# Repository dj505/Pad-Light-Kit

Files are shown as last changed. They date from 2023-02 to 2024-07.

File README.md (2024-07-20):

# Overkill PIU Pad Lighting Kit
An upgrade kit, if you consider a 5x5 RGB LED grid in the center of each panel to be an upgrade.  

Demo

# What is this?
I wanted to make a drop-in kit that replaced the original LEDs in Pump it Up dance pads with fancy StepManiaX-like RGB lighting. **This is only partially that.** Due to a variety of factors, it's not quite as drop-in as I'd hoped, but installation is still rather straightforward!

There are 2 PCB designs being worked on for this project:
* The main "Panel" PCB
    * Contains all the LEDs, with individual microcontrollers per PCB, ensuring they can all work individually.
    * Fully tested, with updated design/gerber files that hardware issues I initially ran into while prototyping.
* The power distrubution PCB
    * Takes a barrel jack and/or bare wires via screw terminals.
    * 5V input only! Make sure your power supply can pump out enough amps to power all the LEDs.
    * 5 outputs, one per arrow on one pad. In the case of DDR/ITG pads, one may be left unused.
    * Also includes footprints for filtering capacitors, which I haven't found to be necessary. Populate with 10uF 0805 capacitors if needed.

Unlike the PicoFX and my other previous hardware projects, this kit is not meant to be hand-soldered, although hand-solder friendly footprints were used where possible. As this likely will not be sold as a pre-made kit any time soon, be aware that it is not a beginner project. PCB manufacturing and assembly costs are rather affordable, but costs from part sourcing and shipping could add up.

# Compatibility & Overview

### This project is designed to be as easy as possible to install, but does require you to do some amount of manual part sourcing. Please pay close attention to power consumption and make sure you source parts that can support the kit.

This project is made for somewhat modern Pump it Up dance pads (FX through LX), but is plug-and-play compatible with:
* All Pump it Up dance pads **after** SD (SD pads used incandescent bulbs and will require some modification for use with this kit)
* In the Groove pads
* Older Dance Dance Revolution pads that use the same 2.54mm pitch connector (double check first!)
Please **pay close attention to the polarity** of the 12V connector printed on the PCB's silkscreen.  
The **yellow wire should go to 12V.** This may involve plugging the cable in upside down. That's okay. Just keep in mind the pins may need to be bent upwards slightly to accept the connector.

Without some modification to the pads and/or this kit, this project is untested or **NOT** plug-and-play compatible with:
* Pump it Up JUMP pads (unfortunate, I know)
* Modern Dance Dance Revolution pads
* Namco "Crapocab" DDR pads
* StepManiaX pads (for several reasons)
* Dance Master Super Station/3DDX
* EZ2Dancer
If the pads you want to use this project with have a **12V DC** wire that powers the original lights, whether it goes to existing LEDs or to an inverter, **this kit will function, but may require you to cut the wires and/or splice in a new connector.** It likely will also not fit the original mounting holes, in which case you'll need to tape it down or something.

Aside from the individual components required for each PCB, you will need:
* As many "Panel" PCBs as your upgrade requires
    * PIU pads require 5 per full pad, 10 in total for a complete setup
    * ITG/DDR pads require 4 per full pad, 8 in total for a complete setup
* A way to supply 5V with up to ~10A maximum current draw (50W or so)
    * This can be either one 5A power supply **per pad**, or one single super beefy power supply for **both pads simultaneously.**
    * If I did my math right, these metrics are based on the peak power comsumption when every single LED is lit up white at full brightness. **Only run your LEDs on full-brightness white for extended periods of time at your own risk; the kit was not developed with this use in mind.** (It would be bright as heck, though)
* Extra wiring to supply power to the new PCBs
    * I recommend 20AWG, anything thinner is not rated for the possible peak power consumption of one panel
* 2 pin male JST connectors (along with metal connector to be crimped to the wires)
    * These are listed here separately from the female connectors in the bill of materials, as you'll need quite a few.
    * 2 connectors are required per panel. One to connect to the lighting PCB, one to connect to the power distribution board.
* A crimping tool compatible with JST XH connectors (optional, but recommended)

# Main panel PCB
A full BOM can be generated using KiCad's schematic editor. Unlike my previous projects, such as the PicoFX or PicoIO, there are a *lot* of components that you will likely need to source yourself. Many of these have LCSC part numbers attached as an example, but are not guaranteed to be available through JLCPCB's assembly service.  
The following components (some of which are not required) are listed per **single** PCB:

### Bill of materials
| Component | Reference | Footprint |Quantity|
|---|---|---|---|
|100nF Capacitor |C1, C2, C4, C5, C7-C9, C12, C14, C15 |SMD 0402 |10 |
|1uF Capacitor |C3, C6 |SMD 0402 |2 |
|27pF Capacitor |C10, C11 |SMD 0402 |2 |
|10uF Capacitor |C13, C16 |SMD 0402 |2 |
|WS2812B-V5 LED (!) |D1-10, D12-26 |PLCC4 5x5mm |25 |
|SS34 Diode |D27 |DO-214AC |1 |
|Green LED |D28 |SMD 0805 |1 |
|nSMD025 Fuse |F1 |SMD 1206 |1 |
|3 Pin Header \* |J1 |2.54mm Pitch |1 |
|USB Type C Port |J2 |G-Switch GT-USB 7010ASV |1 |
|2 Pin JST XH |J3 |2.50mm Pitch |1 |
|2x6 Pin Header \* |J4 |2.54mm Pitch |1 |
|Molex 35312-0760 \~\~ |J5 |N/A |1 |
|Molex Mini-Fit Jr \~\~ |J6-J9 |N/A |4 |
|2 Pin Header \~ |J10 |2.54mm Pitch, **Horizontal**|1 |
|3 Pin Header \*\* |J11, J12 |1.27mm Pitch, Not Required  |2 |
|1k Ohm Reistor |R1, R8, R10 |SMD 0402 |3 |
|10k Ohm Resistor |R2 |SMD 0402 |1 |
|10K Ohm Resistor \*\* |R3 |SMD 0402 (for SPI flash) |1 |
|27 Ohm Resistor |R4, R5 |SMD 0402 |2 |
|5.1k Ohm Resistor |R6, R7 |SMD 0402 |2 |
|3k Ohm Resistor |R9 |SMD 0402 |1 |
|Tactile Button Switch |SW1, SW2 |6mm x 6mm |2 |
|W25Q32JVSS (or equivalent) |U1 |SOIC-8 |1 |
|Raspberry Pi RP2040 |U2 |QFN-56 |1 |
|NCP1117 3.3V Output Regulator|U3 |SOT-223-3 |1 |
|12.000MHz Crystal Oscillator |Y1 |HC49 |1 |

(!) WS2812B-V5 LEDs don't require external capacitors, so there are no footprints for them on this board. Earlier revisions may not work properly without these capacitors.
\* Optional  
\*\* Do Not Fit (only required if a part malfunctions without it)  
\~ Required for old-style pads (FX and earlier)  
\~\~ Required for new-style pads (CX/TX and newer)  

All **SMD 0402** parts use hand-solder footprints in just in case, however if you do not own a reflow oven or hot air soldering station, please consider using an assembly service available through companies like PCBWay or JLCPCB for a better and more realiable end result. It does cost extra, but will be far less time consuming and far more reliable than soldering hundreds of components by hand.

# Power PCB
This part is extremely basic and just supplies power to the panels. Each PCB should be capable of supplying up to 8A, enough to power all 5 panels. Just make sure to hook it up to a power supply capable of delivering the necessary wattage.

### Bill of materials
| Component | Reference | Footprint |Quantity|
|---|---|---|---|
|10uF Capacitor \* |C1-C5 |SMD 0805 |5 |
|2 Pin Screw Terminal \*\* |J1 |5mm Plugin Terminal |1 |
|DC Barrel Jack \*\* |J2 |2.5mm inner, 6.4mm Outer |1 |
|2 Pin JST XH |J3-J7 |2.50mm Pitch |5 |

\* Option/not strictly necessary. Serves a purpose, but shouldn't affect functionality if missing.  
\*\* Denotes parts that are interchangeable depending on how you want to power the board

This board lacks mounting holes and is intended to just be attached somewhere near the foot PCB or power supply with double sided tape. Placement is up to you. Footprints for a screw terminal and a DC jack are provided, depending on which is more suited to your use case. You could even solder the power wires straight to the PCB if you really want to.  

JST XH connectors with 20AWG wire will need to be routed from the power distrubution PCB to every individual panel PCB. This shouldn't be all that difficult, just a little extra time consuming. Having a crimping tool would make this far easier.

# Very Important Notes
**(Seriously, you're going to want to double check these!)**

### This kit will require dedicated external power, and there's no safe way around that!
This kit bumps the LED count up to 125 per pad. Stock pads have around 40 or fewer depending on pad model. Please don't try to power this off the cab's original 12V line! The original 22AWG wire is rated for roughly 0.92A. This kit can potentially draw up to 1A per panel, or 5A total per pad. Plus, the 12V line is used for signalling purposes with this kit, and it won't function correctly without it. **I've measured a draw of 0.874A for a single panel lit up white at full brightness, however this may not be consistent from build to build.** While 10A total is a worst-case scenario, be sure to stick to the following guidelines:  
* Make sure you use a power supply that's capable of supplying the necessary amount of power required by this kit, and pick a wire gauge capable of carrying the amount of power needed for each panel. I would recommend 20AWG.  
* You'll need a way to run power into the pads. If I can come up with a more elegant solution I'll be sure to post it in detail, but the holes present in the bottom corners of each arrow are safe bets as entry points for your wires.
* Even if you don't plan on running these at high enough power to draw 5A per pad (or the maximum you have measured on your own), don't skimp out on a power supply. Overdrawing the power supply will cause it to get uncomfortably warm (or worse), and will eventually destroy it. Spend the extra few bucks for safety!

### Make sure you use a bright solder mask!
White is recommended, green and others may also work, but black solder mask isn't known to be very reflective. It won't make a very big difference, but it will definitely look better and brighter.

### If you own a multimeter, check the voltage of the 12V line!
These boards get their "turn on and start animating" signal from the original 12V wiring that's meant to power the stock LEDs/inverters/what have you. To make this safe for the 3.3V RP2040 chip, a voltage divider is used. Until this design is eventually replaced with an optoisolator or other component, **you should do the following:**  
1. Unplug the stock LED
2. Hook up a voltmeter or a multimeter in DC mode to the connector
3. Ensure the connector supples **no less than 10V** and **no more than 13.2V** when supplying power  
If your measurement falls outside of this range and the power supply in your cab isn't adjustable, you may need to use different reistors for the voltage divider circuit.

If the connector is not supplying enough power, the microcontroller won't read it as a "high" signal to start animating the lights. If it's *too* high, you risk damaging the microcontroller. I've haven't seen any machines deviate from this general range before, so chances are you're fine, but make sure to double check. If your machine has a variable voltage power supply **and you know what you're doing**, you can adjust it slightly to fit within the safe range.

# Firmware Setup
This project runs on [CircuitPython for the Raspberry Pi Pico.](https://circuitpython.org/board/raspberry_pi_pico/). I'm not quite clever enough to create a special CircuitPython build specifically for this project yet, maybe one day!

1. Download the .uf2 file for CircuitPython. This project was developed using 7.3.3, but in between writing the firmware and actually receiving all the parts for a kit, 8.0.0 was released as a stable version, so the following instructions have been updated.
2. Plug the board into your PC. The BOOTSEL button shouldn't need to be held as the board should not yet be programmed. If for some reason it already is, use the BOOTSEL button.
3. The board should pop up as a USB mass storage device. Drag and drop the .uf2 file onto it. After a moment, it should disconnect, and you should see a "CIRCUITPY" drive appear in its place.
4. Open the "CIRCUITPY" drive, and copy the contents of this repository's "Firmware" directory onto it, overwriting code.py.
5. Download the [CircuitPython library bundle](https://circuitpython.org/libraries) that matches the version of CircuitPython you installed.
    * Look inside the "lib" directory for an "asyncio" folder. Copy this to the CIRCUITPY drive's "lib" folder.
    * Do the same for "adafruit_pixelbuf.mpy", "adafruit_ticks.mpy", and "neopixel.mpy".
6. Create your animations. See the instructions in /Firmware/README.md or use the included example animations.
    * Your animation should be a bitmap file titled "image.bmp" and located in the "bitmap" directory.
    * By default, there won't be a "bitmap" directory. You'll need to create this by hand or copy over the example one.
7. You're done! If everything is assembled and set up properly, your animations should now work, and the panel is ready to be installed.

# Installation
After assembling and setting up the firmware for each of the panels, actually installing them is the easy part. I'll update this section with photos when I have some.

1. Unplug and remove the original LEDs, and replace them with the new boards.
    * If the mounting holes *do* line up, use the original screws to secure the new boards in place.
    * If the mounting holes *don't* line up, double sided tape will do the trick!
    * You may have to remove some original parts to make room, depending on the pad. This mostly applies to much older pads that have fluorescent lights hooked up to inverters. Carefully remove these (they may be fragile!) and set them aside.
2. Find a power supply, and plan out where the wires are going to go.
    * I find the easiest way to do this is to hide the power supply underneath the dance pad and run the cable coming from the low voltage side in through the one of the 4 holes in the bottom of one of the arrow panels.
    * I would not recommend routing any AC wiring or power supply units inside of the dance pads for safety reasons. It's much safer to run the low voltage DC side in alone.
3. Mount the power distribution PCB.
    * Make sure it's within easy reach of the cable you'll be using to power it.
    * The placement here is entirely up to your discretion, just put it somewhere that allows you to easily run all the necessary wires. I mounted mine under the center panel.
    * This PCB has no mounting holes, since you'll be using double sided tape or other similar adhesive to mount it. Make sure any exposed contacts on the bottom are trimmed down and/or covered and so they do not make contact with the pad frame.
4. Run wires from the distribution board's outputs to each of your panels.
    * If you know what you're doing, and you thoroughly test the power consumption of your components, be sure to use a wire rated for the power draw. Otherwise, I recommend 20AWG wire. I personally measured a 0.874A peak power draw, but your build may differ.
    * You can either try to source wires with JST XH connectors on either end, or you can crimp these yourself.
    * If you crimp these yourself, buy a crimping tool! They don't cost a lot and they make things way way less of a pain. (They're still kind of a pain, though.)
    * Double check that the positive/negative connections line up on both sides of your wires.
5. Fire it up and give it a test!
    * If something doesn't work, move onto the troubleshooting section.

# Jumper Options
These jumpers are currently unused. Please feel free to reach out and suggest features!

# Bypassing the Voltage Divider
There's a small set of jumper pads underneath and to the right of the connector for the 12V light header header that is meant to bypass the voltage divider. This is meant to allow the panel to be easily used in home pads or DIY pads using an Arduino-like main board. **Do not bridge this jumper if using anything higher than a 3.3V to control the lights.**

To use this feature, you must:
* Make sure you remove resistors R9 and R10 underneath the header if they are currently installed. Otherwise, exclude these components during the initial asssembly.
* Make sure the GPIO you're going to connect this to operates at a **3.3 volt logic level!** The RP2040 is **not 5V tolerant** and applying 5V to the GPIO can cause irreversible damage.

If you plan to use a 5V microcontroller, you must **not** bridge the jumper, and should instead adjust the values of the resistors in the voltage divider accordingly.

# Troubleshooting
This list will be expanded as potential issues crop up.
* **No lights or pattern on the LED grid**
    1. Make sure the bitmap is in the "bitmap" directory, and is named "bitmap.bmp".
    2. Check that external power is connected. A USB connection will not power the LEDs.
    3. Re-export your bitmap through GIMP with the correct settings:
        * 24-bit colour depth
        * Run-length encoding **disabled**
        * Saving colour space information doesn't seem to make a difference, but if in doubt, disable it
* **Pattern displays, but doesn't look right**
    1. Make sure your spritesheet is made up of exactly 5x5 pixel sprites, all of which should be stacked vertically. More than one column will not work.
    2. Re-export your bitmap through GIMP with the correct settings. See step 3 under "No lights or pattern on the LED grid."
* **All the LEDs past a certain point fail to light up**
    1. Check the solder points on and around the LED where the chain is broken.
        * The strip goes from left to right on the first row, then right to left on the second row, zigzagging back and forth.
        * If any single LED is not properly connected, it can either light up but not send a signal to the next one, or fail to light up itself.
        * Carefully re-solder any bad connections and test again.
    2. Ensure the LEDs are oriented correctly.
        * With the USB port on the top left corner, the notch on every LED should be on the bottom right side.
        * Any LEDs that aren't oriented properly will need to be desoldered and rotated.
* **One single LED doesn't light up, but the rest work**
    1. Add some flux to each leg of the LED and reflow the solder.
        * Screwing the PCB down into the pad may slightly bend it, causing a poor connection on one or more LEDs.
        * Reflowing the solder usually fixes this fault. Current revisions of the PCB with slightly larger mounting holes should be less susceptible to it.

# Credits
Thanks to:
- [sugoku](https://github.com/sugoku) for the Molex 35312 series footprints

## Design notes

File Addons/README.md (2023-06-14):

# Addons
Various addons for the Overkill Pad Lighting Kit

## What do these do?
* Comms **(Rev. 2 and earlier panel PCBs)**
  * Adds RS485 communication to each board to sync lighting data.
* Comms Controller **(Rev. 2 and earlier panel PCBs)**
  * Will act as a central unit for uploading new lighting patterns, ideally using a Raspberry Pi Pico W hosting a web interface.

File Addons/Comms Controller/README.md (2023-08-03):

# Comms Controller
This addon is meant for **all current revisions** of the Pad Light Kit main board. As of writing, the current revision is **Rev. 3.**

This addon allows patterns to be uploaded to the main board(s) over RS485. Don't mix up the RS485 and power connectors!

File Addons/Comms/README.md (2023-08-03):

# Comms
This addon is made for **panel PCB rev. 2 and earlier**. Revision 3 has this functionality built-in and it is no longer necessary.

The "Comms" addon is meant to allow each panel to communicate robustly using RS485 through SP3485 chips to synchronize lighting patterns and other settings.

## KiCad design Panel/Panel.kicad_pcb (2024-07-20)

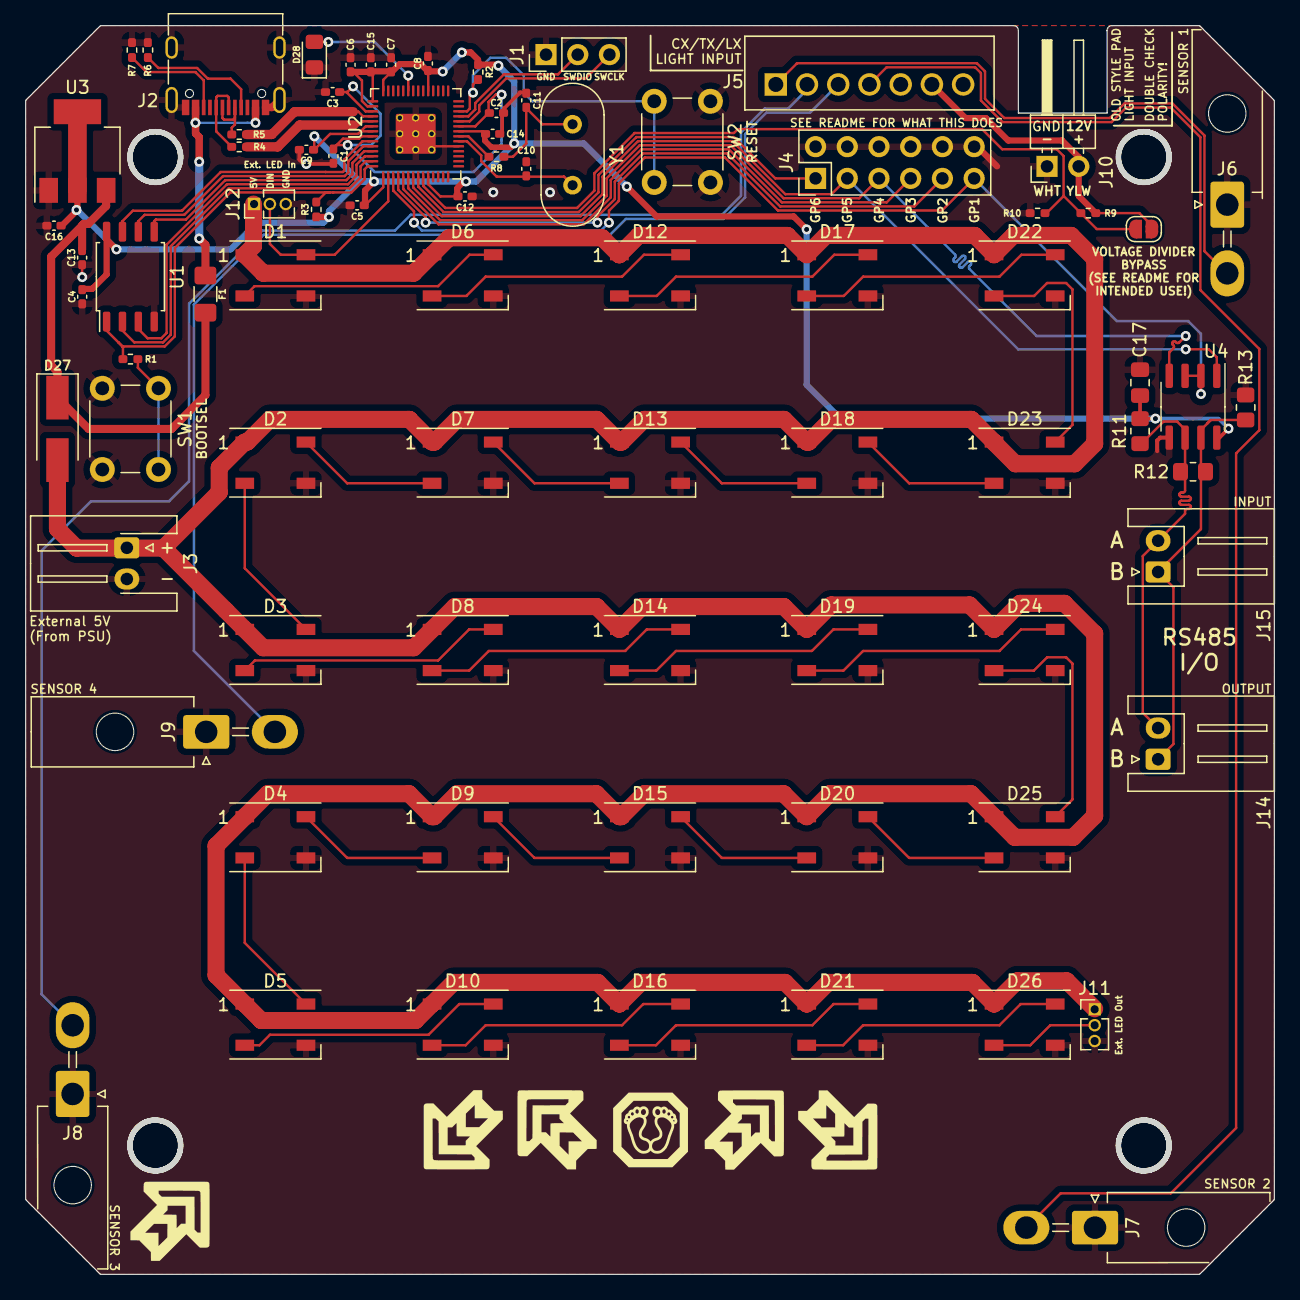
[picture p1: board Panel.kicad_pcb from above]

Board: 2 copper layers, 100.0 x 100.0 mm, 80 parts (0 on the bottom side), 66 nets.

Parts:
C1, C2, C4, C5, C7, C8, C9, C12, C14, C15: 100nF; C_0402_1005Metric_Pad0.74x0.62mm_HandSolder
C3, C6: 1uF; C_0402_1005Metric_Pad0.74x0.62mm_HandSolder
C10, C11: 27pF; C_0402_1005Metric_Pad0.74x0.62mm_HandSolder
C13, C16: 10uF; C_0402_1005Metric_Pad0.74x0.62mm_HandSolder
C17: 100nF; C_0805_2012Metric_Pad1.18x1.45mm_HandSolder
D1, D2, D3, D4, D5, D6, D7, D8, D9, D10, D12, D13, D14, D15, D16, D17, D18, D19, D20, D21, D22, D23, D24, D25, D26: WS2812B; LED_WS2812B_PLCC4_5.0x5.0mm_P3.2mm
D27: SS34; D_SMA_Handsoldering
D28: LED_Small; LED_0805_2012Metric_Pad1.15x1.40mm_HandSolder
F1: 500mA; Fuse_1206_3216Metric_Pad1.42x1.75mm_HandSolder
J1: Conn_01x03; PinHeader_1x03_P2.54mm_Vertical
J2: USB_C_Receptacle_USB2.0; USB_C_Receptacle_G-Switch_GT-USB-7010ASV
J3: Conn_01x02; JST_XH_S2B-XH-A-1_1x02_P2.50mm_Horizontal
J4: Conn_02x06_Odd_Even; PinHeader_2x06_P2.54mm_Vertical
J5: Conn_01x07; 35312-0760
J6, J7, J8, J9: Conn_01x02; Molex_Mini-Fit_Jr_5569-02A2_2x01_P4.20mm_Horizontal
J10: Conn_01x02; PinHeader_1x02_P2.54mm_Horizontal
J11, J12: Conn_01x03; PinHeader_1x03_P1.27mm_Vertical
J14, J15: Conn_01x02; JST_XH_S2B-XH-A_1x02_P2.50mm_Horizontal
JP1: Jumper_2_Open; SolderJumper-2_P1.3mm_Open_RoundedPad1.0x1.5mm
R1, R8, R10: 1k; R_0402_1005Metric_Pad0.72x0.64mm_HandSolder
R2: 10k; R_0402_1005Metric_Pad0.72x0.64mm_HandSolder
R3: DNF; R_0402_1005Metric_Pad0.72x0.64mm_HandSolder
R4, R5: 27 Ohm; R_0402_1005Metric_Pad0.72x0.64mm_HandSolder
R6, R7: 5.1k; R_0402_1005Metric_Pad0.72x0.64mm_HandSolder
R9: 3k; R_0402_1005Metric_Pad0.72x0.64mm_HandSolder
R11, R13: 4.7k; R_0805_2012Metric_Pad1.20x1.40mm_HandSolder
R12: 120; R_0805_2012Metric_Pad1.20x1.40mm_HandSolder
SW1, SW2: SW_Push; SW_PUSH_6mm
U1: W25Q32JVSS; SOIC-8_5.23x5.23mm_P1.27mm
U2: RP2040; RP2040-QFN-56
U3: NCP1117-3.3_SOT223; SOT-223-3_TabPin2
U4: SP3485EN; SOIC-8_3.9x4.9mm_P1.27mm
Y1: 12.000MHz; Crystal_HC49-4H_Vertical

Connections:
+1V1: C1.1, C2.1, C3.1, U2.23 (DVDD), U2.45 (VREG_VOUT), U2.50 (DVDD)
+3V3: C4.1, C5.1, C6.1, C7.1, C8.1, C9.1, C12.1, C14.1, C15.1, C16.1, C17.1, R2.1, R3.1, R11.1, U1.8 (VCC), U2.1 (IOVDD), U2.10 (IOVDD), U2.22 (IOVDD), U2.33 (IOVDD), U2.42 (IOVDD), U2.43 (ADC_AVDD), U2.44 (VREG_IN), U2.48 (USB_VDD), U2.49 (IOVDD), U3.2 (VO), U4.8 (VCC)
+5V: C13.1, D27.1 (K), F1.2, U3.3 (VI)
/RS485_A: J14.2, J15.2, R11.2, R12.1, U4.6 (A)
/RS485_B: J14.1, J15.1, R12.2, R13.1, U4.7 (B)
Ext 5V: D1.1 (VDD), D2.1 (VDD), D3.1 (VDD), D4.1 (VDD), D5.1 (VDD), D6.1 (VDD), D7.1 (VDD), D8.1 (VDD), D9.1 (VDD), D10.1 (VDD), D12.1 (VDD), D13.1 (VDD), D14.1 (VDD), D15.1 (VDD), D16.1 (VDD), D17.1 (VDD), D18.1 (VDD), D19.1 (VDD), D20.1 (VDD), D21.1 (VDD), D22.1 (VDD), D23.1 (VDD), D24.1 (VDD), D25.1 (VDD), D26.1 (VDD), D27.2 (A), J3.1, J11.1, J12.1
GND: C1.2, C2.2, C3.2, C4.2, C5.2, C6.2, C7.2, C8.2, C9.2, C10.1, C11.1, C12.2, C13.2, C14.2, C15.2, C16.2, C17.2, D1.3 (VSS), D2.3 (VSS), D3.3 (VSS), D4.3 (VSS), D5.3 (VSS), D6.3 (VSS), D7.3 (VSS), D8.3 (VSS), D9.3 (VSS), D10.3 (VSS), D12.3 (VSS), D13.3 (VSS), D14.3 (VSS), D15.3 (VSS), D16.3 (VSS), D17.3 (VSS), D18.3 (VSS), D19.3 (VSS), D20.3 (VSS), D21.3 (VSS), D22.3 (VSS), D23.3 (VSS), D24.3 (VSS), D25.3 (VSS), D26.3 (VSS), D28.1 (K), J1.1, J2.A1 (GND), J2.A12 (GND), J2.B1 (GND), J2.B12 (GND), J2.S1 (SHIELD), J3.2, J4.2, J4.4, J4.6, J4.8, J4.10, J4.12, J5.7, J6.1, J7.1, J8.1, J9.1, J10.1, J11.3, J12.3, R6.2, R7.1, R10.2, R13.2, SW1.1, SW2.2, U1.4 (GND), U2.19 (TESTEN), U2.57 (GND), U3.1 (GND), U4.5 (GND)
GPIO0: D1.4 (DIN), J12.2, U2.2 (GPIO0)
GPIO1: J4.11, U2.3 (GPIO1), U4.2 (~RE), U4.3 (DE)
GPIO2: J4.9, U2.4 (GPIO2)
GPIO3: J4.7, U2.5 (GPIO3)
GPIO4: J4.5, U2.6 (GPIO4), U4.4 (DI)
GPIO5: J4.3, U2.7 (GPIO5), U4.1 (RO)
GPIO6: J4.1, U2.8 (GPIO6)
GPIO7: JP1.1 (A), R9.2, R10.1, U2.9 (GPIO7)
LIGHT EN: J5.6, J10.2, JP1.2 (B), R9.1
unnamed: C11.2, R8.1, Y1.1
unnamed: D1.2 (DOUT), D6.4 (DIN)
unnamed: D2.4 (DIN), D7.2 (DOUT)
unnamed: D2.2 (DOUT), D3.4 (DIN)
unnamed: D3.2 (DOUT), D8.4 (DIN)
unnamed: D4.4 (DIN), D9.2 (DOUT)
unnamed: D4.2 (DOUT), D5.4 (DIN)
unnamed: D5.2 (DOUT), D10.4 (DIN)
unnamed: D10.2 (DOUT), D16.4 (DIN)
unnamed: D6.2 (DOUT), D12.4 (DIN)
unnamed: D12.2 (DOUT), D17.4 (DIN)
unnamed: D13.4 (DIN), D18.2 (DOUT)
unnamed: D7.4 (DIN), D13.2 (DOUT)
unnamed: D8.2 (DOUT), D14.4 (DIN)
unnamed: D14.2 (DOUT), D19.4 (DIN)
unnamed: D15.4 (DIN), D20.2 (DOUT)
unnamed: D9.4 (DIN), D15.2 (DOUT)
unnamed: D16.2 (DOUT), D21.4 (DIN)
unnamed: D17.2 (DOUT), D22.4 (DIN)
unnamed: D18.4 (DIN), D23.2 (DOUT)
unnamed: D19.2 (DOUT), D24.4 (DIN)
unnamed: D20.4 (DIN), D25.2 (DOUT)
unnamed: D21.2 (DOUT), D26.4 (DIN)
unnamed: D22.2 (DOUT), D23.4 (DIN)
unnamed: D24.2 (DOUT), D25.4 (DIN)
unnamed: D26.2 (DOUT), J11.2
unnamed: D28.2 (A), U2.37 (GPIO25)
unnamed: F1.1, J2.A4 (VBUS), J2.A9 (VBUS), J2.B4 (VBUS), J2.B9 (VBUS)
unnamed: J2.A5 (CC1), R6.1
unnamed: J2.B5 (CC2), R7.2
unnamed: R1.1, SW1.2
unnamed: R5.1, U2.46 (USB_DM)
unnamed: R4.1, U2.47 (USB_DP)
QSPI_SCLK: U1.6 (CLK), U2.52 (QSPI_SCLK)
QSPI_SD0: U1.5 (DI(IO0)), U2.53 (QSPI_SD0)
QSPI_SD1: U1.2 (DO(IO1)), U2.55 (QSPI_SD1)
QSPI_SD2: U1.3 (IO2), U2.54 (QSPI_SD2)
QSPI_SD3: U1.7 (IO3), U2.51 (QSPI_SD3)
QSPI_SS: R1.2, R3.2, U1.1 (~CS), U2.56 (QSPI_SS)
RUN: R2.2, SW2.1, U2.26 (RUN)
SENSOR 1: J5.1, J6.2
SENSOR 2: J5.4, J7.2
SENSOR 3: J5.2, J8.2
SENSOR 4: J5.3, J9.2
SWCLK: J1.3, U2.24 (SWCLK)
SWDIO: J1.2, U2.25 (SWD)
USB D+: J2.A6 (D+), J2.B6 (D+), R4.2
USB D-: J2.A7 (D-), J2.B7 (D-), R5.2
XIN: C10.2, U2.20 (XIN), Y1.2
XOUT: R8.2, U2.21 (XOUT)

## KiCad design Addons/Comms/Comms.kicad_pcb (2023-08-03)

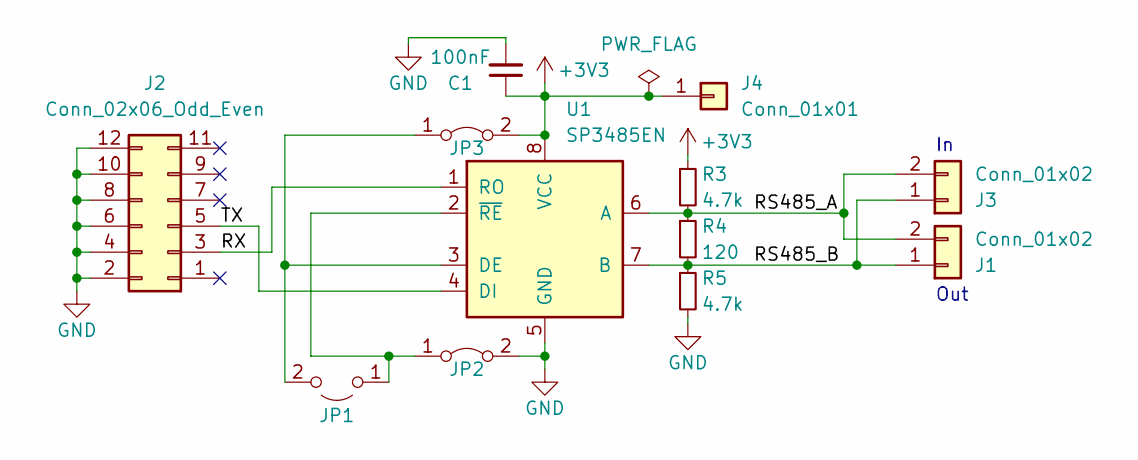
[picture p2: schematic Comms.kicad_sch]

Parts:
C1: 100nF; C_0805_2012Metric_Pad1.18x1.45mm_HandSolder; LCSC C49678
J1, J3: Conn_01x02; JST_XH_S2B-XH-A_1x02_P2.50mm_Horizontal
J2: Conn_02x06_Odd_Even; PinHeader_2x06_P2.54mm_Vertical
J4: Conn_01x01; PinHeader_1x01_P2.54mm_Vertical
JP1: Jumper_2_Open; SolderJumper-2_P1.3mm_Open_RoundedPad1.0x1.5mm
JP2, JP3: Jumper_2_Bridged; SolderJumper-2_P1.3mm_Bridged_RoundedPad1.0x1.5mm
R3, R5: 4.7k; R_0805_2012Metric_Pad1.20x1.40mm_HandSolder; LCSC C17673
R4: 120; R_0805_2012Metric_Pad1.20x1.40mm_HandSolder; LCSC C17437
U1: SP3485EN; SOIC-8_3.9x4.9mm_P1.27mm; LCSC C8963

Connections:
+3V3: C1.1, J4.1, JP3.2 (B), R3.1, U1.8 (VCC)
/RS485_A: J1.2, J3.2, R3.2, R4.1, U1.6 (A)
/RS485_B: J1.1, J3.1, R4.2, R5.1, U1.7 (B)
/RX: J2.3, U1.1 (RO)
/TX: J2.5, U1.4 (DI)
GND: C1.2, J2.2, J2.4, J2.6, J2.8, J2.10, J2.12, JP2.2 (B), R5.2, U1.5 (GND)
unnamed: JP1.1 (A), JP2.1 (A), U1.2 (~RE)
unnamed: JP1.2 (B), JP3.1 (A), U1.3 (DE)

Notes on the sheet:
Out

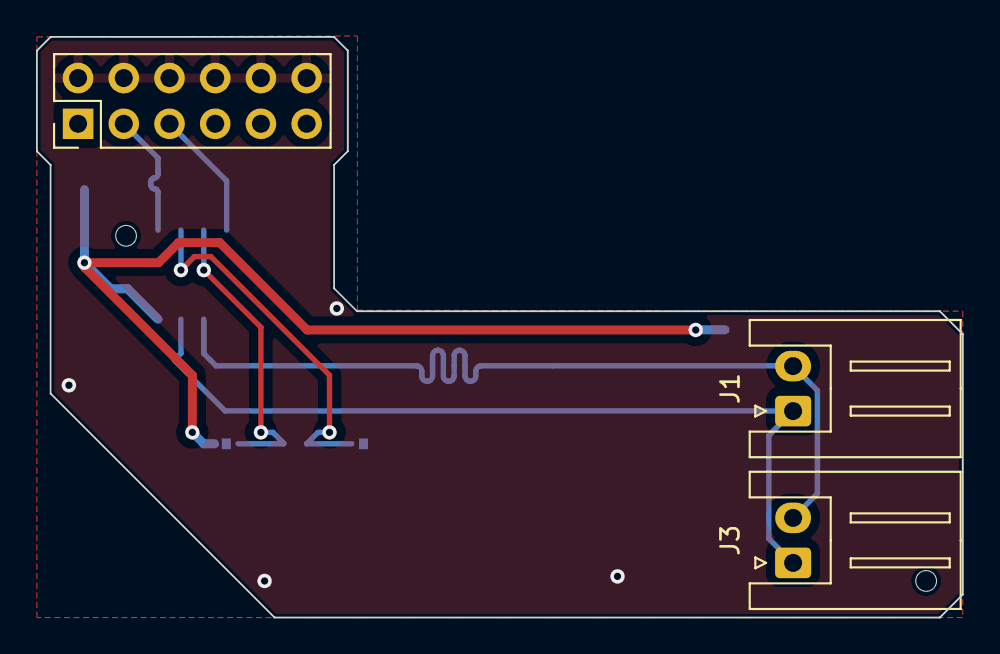
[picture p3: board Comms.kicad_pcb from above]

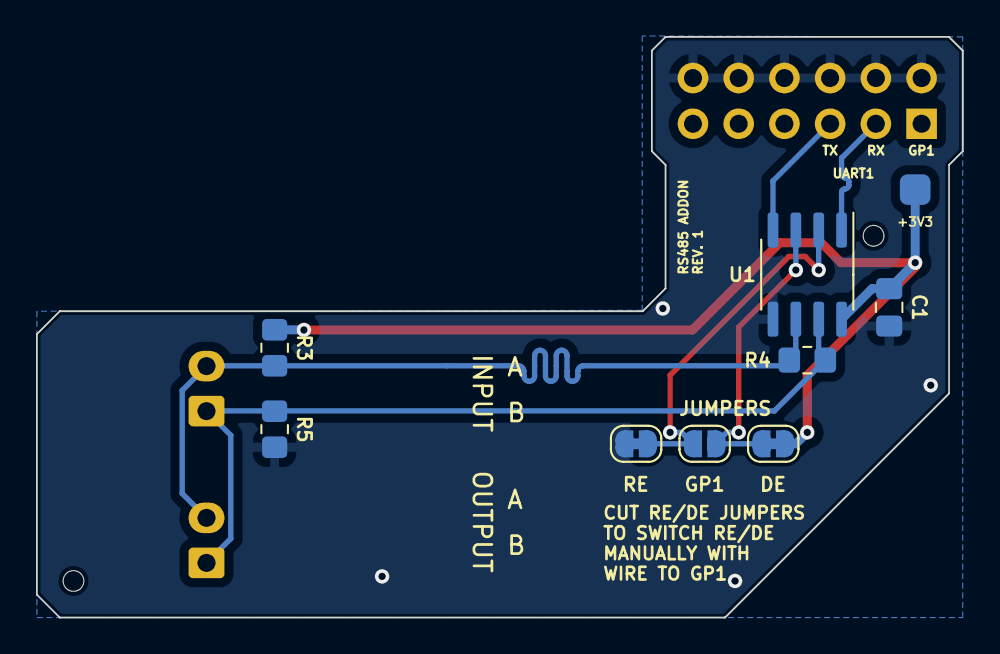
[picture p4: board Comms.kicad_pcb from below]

Board: 2 copper layers, 51.4 x 32.3 mm, 12 parts (9 on the bottom side), 8 nets.

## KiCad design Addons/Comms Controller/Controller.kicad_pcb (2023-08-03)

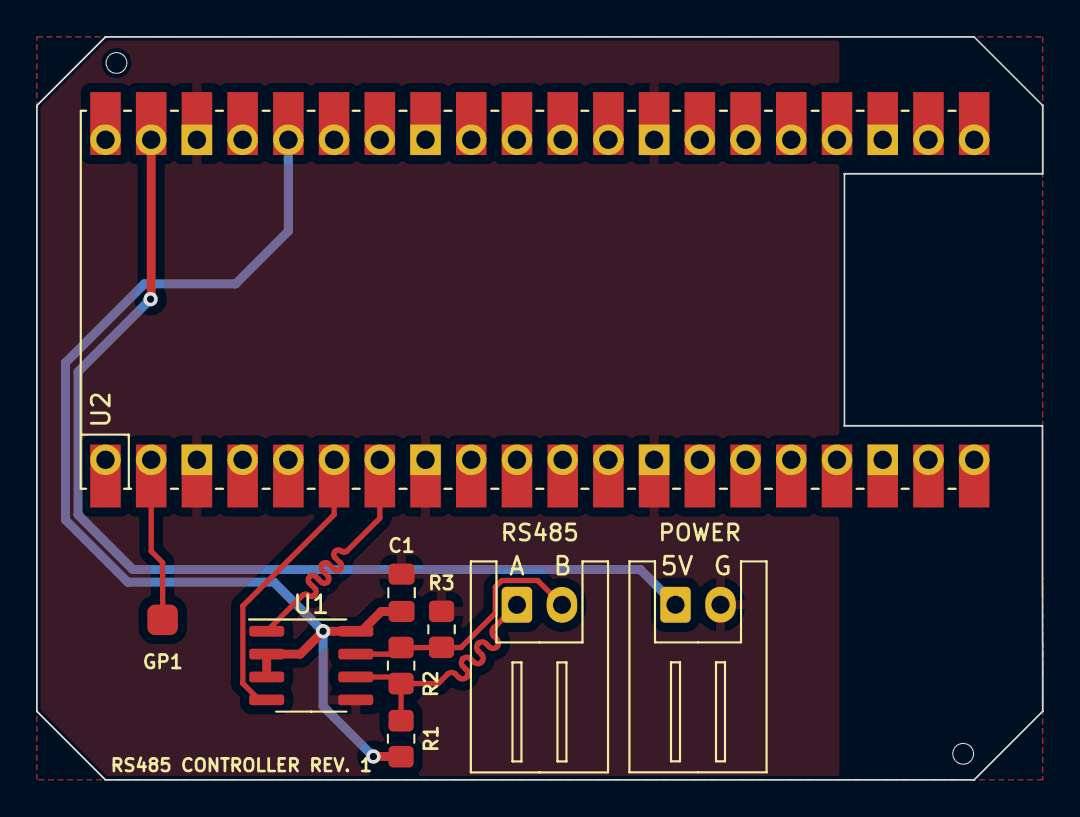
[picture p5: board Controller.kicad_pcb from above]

Board: 2 copper layers, 55.9 x 41.3 mm, 9 parts (0 on the bottom side), 8 nets.

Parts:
C1: 100nF; C_0805_2012Metric_Pad1.18x1.45mm_HandSolder
J1: GP1 Bodge; PinSocket_1x01_P2.54mm_Vertical
J2, J3: Conn_01x02; JST_XH_S2B-XH-A_1x02_P2.50mm_Horizontal
R1, R3: 4.7k; R_0805_2012Metric_Pad1.20x1.40mm_HandSolder
R2: 120; R_0805_2012Metric_Pad1.20x1.40mm_HandSolder
U1: SP3485EN; SOIC-8_3.9x4.9mm_P1.27mm
U2: Pico; RPi_Pico_SMD_TH

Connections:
+3V3: C1.1, R1.1, U1.2 (~RE), U1.3 (DE), U1.8 (VCC), U2.36 (3V3)
+5V: J3.1, U2.39 (VSYS)
/RS485_A: J2.1, R1.2, R2.1, U1.6 (A)
/RS485_B: J2.2, R2.2, R3.1, U1.7 (B)
GND: C1.2, J3.2, R3.2, U1.5 (GND), U2.3 (GND), U2.8 (GND), U2.13 (GND), U2.18 (GND), U2.23 (GND), U2.28 (GND), U2.38 (GND)
unnamed: J1.1, U2.2 (GPIO1)
RX: U1.1 (RO), U2.7 (GPIO5)
TX: U1.4 (DI), U2.6 (GPIO4)

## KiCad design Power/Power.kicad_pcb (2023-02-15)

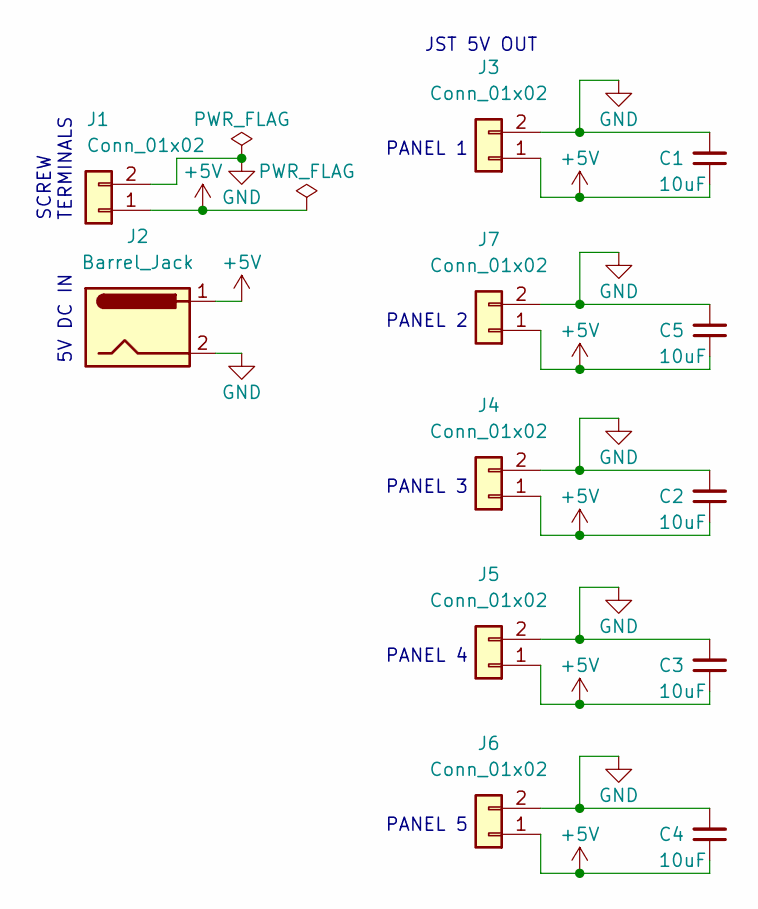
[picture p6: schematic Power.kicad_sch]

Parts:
C1, C2, C3, C4, C5: 10uF; C_0805_2012Metric_Pad1.18x1.45mm_HandSolder
J1: Conn_01x02; TerminalBlock_bornier-2_P5.08mm
J2: Barrel_Jack; BarrelJack_CUI_PJ-063AH_Horizontal
J3, J4, J5, J6, J7: Conn_01x02; JST_XH_B2B-XH-A_1x02_P2.50mm_Vertical

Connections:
+5V: C1.1, C2.1, C3.1, C4.1, C5.1, J1.1, J2.1, J3.1, J4.1, J5.1, J6.1, J7.1
GND: C1.2, C2.2, C3.2, C4.2, C5.2, J1.2, J2.2, J2.MP, J3.2, J4.2, J5.2, J6.2, J7.2

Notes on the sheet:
PANEL 4
JST 5V OUT
SCREW TERMINALS
PANEL 2
PANEL 1
5V DC IN
PANEL 3
PANEL 5

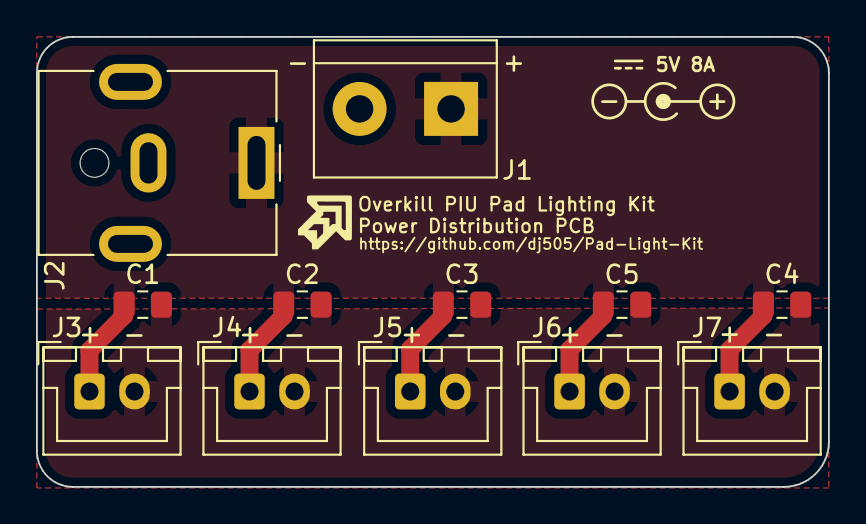
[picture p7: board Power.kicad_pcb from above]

Board: 2 copper layers, 44.0 x 25.0 mm, 12 parts (0 on the bottom side), 2 nets.

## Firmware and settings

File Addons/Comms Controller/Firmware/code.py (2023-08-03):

import board
import busio
import digitalio
import time
import ipaddress
import wifi
from adafruit_httpserver import Server, Request, Response, POST
import socketpool
import re
import json
import binascii

uart = busio.UART(board.GP4, board.GP5, baudrate=9600)

# Wifi stuff
ssid = "dkpepper"
pswd = "7808607880"
ip = "10.0.0.234"

ipv4 =  ipaddress.IPv4Address(ip)
netmask =  ipaddress.IPv4Address("255.255.255.0")
gateway =  ipaddress.IPv4Address("10.0.0.1")
wifi.radio.set_ipv4_address(ipv4=ipv4,netmask=netmask,gateway=gateway)
#  connect to your SSID
wifi.radio.connect(ssid, pswd)

print("Connected to WiFi")
pool = socketpool.SocketPool(wifi.radio)
server = Server(pool, "/static", debug=True)

def webpage():
    html = f"""
    <!DOCTYPE html>
        <html>
            <head>
                <meta http-equiv="Content-type" content="text/html;charset=utf-8">
                <meta name="viewport" content="width=device-width, initial-scale=1">
                <script>
                  document.addEventListener("DOMContentLoaded", function() {{
                    var DL = document.getElementById('DL');
                    var UL = document.getElementById('UL');
                    var CN = document.getElementById('CN');
                    var UR = document.getElementById('UR');
                    var DR = document.getElementById('DR');

                    function handleFileUpload(event) {{
                      event.preventDefault();
                      const file = event.target.files[0];
                      const boardID = event.currentTarget.ID
                      const reader = new FileReader();

                      reader.onload = function() {{
                        const base64Image = reader.result.split(',')[1];
                        console.log(base64Image);
                        sendImageToServer(base64Image, boardID);
                      }};
                      reader.readAsDataURL(file);
                    }};

                    function sendImageToServer(base64Image, ID) {{
                      const data = {{
                        image: base64Image,
                        boardID: ID
                      }};

                      const jsonData = JSON.stringify(data);

                      console.log(jsonData);

                      // Send the POST request
                      fetch('http://{ip}', {{
                        method: 'POST',
                        mode: 'cors',
                        headers: {{
                          'Content-Type': 'application/json'
                        }},
                        body: jsonData
                      }})
                      .then(response => response.json())
                      .then(result => {{
                        // Handle the response from the server
                        console.log('Server response:', result);
                      }})
                      .catch(error => {{
                        // Handle any errors
                        console.error('Error:', error);
                      }});
                    }};

                    DL.addEventListener('change', handleFileUpload);
                    DL.ID = "DL"
                    UL.addEventListener('change', handleFileUpload);
                    UL.ID = "UL"
                    CN.addEventListener('change', handleFileUpload);
                    CN.ID = "CN"
                    UR.addEventListener('change', handleFileUpload);
                    UR.ID = "UR"
                    DR.addEventListener('change', handleFileUpload);
                    DR.ID = "DR"
                  }});
                </script>
            </head>
            <body>
                <title>Pad Light Kit Thing :)</title>
                <h1>Overkill Pad Light Kit File Upload</h1>
                <form id="uploadForm">
                    <label for="DL">DownLeft Pattern</label><br>
                    <input type="file" id="DL"><br><br>
                    <label for="UL">UpLeft Pattern</label><br>
                    <input type="file" id="UL"><br><br>
                    <label for="CN">Center Pattern</label><br>
                    <input type="file" id="CN"><br><br>
                    <label for="UR">UpRight Pattern</label><br>
                    <input type="file" id="UR"><br><br>
                    <label for="DR">DownRight Pattern</label><br>
                    <input type="file" id="DR"><br><br>
                    <button>Upload</button>
                </form>
                <p id="opTag"></p>
            </body>
        </html>
    """
    return html

def decode_image(data):
    image = binascii.a2b_base64(data)
    return image

def uart_write(boardid, imagedata):
    n = 32
    strbytes = bytearray(f"<{boardid},{imagedata}>")
    bytechunks = [strbytes[i:i + n] for i in range(0, len(strbytes), n)]
    print(bytechunks)
    print(f"Writing UART Data")
    for chunk in bytechunks:
        print(chunk)
        uart.write(chunk)
        time.sleep(0.2)
    return True

@server.route("/")
def base(request: Request):
    return Response(request, f"{webpage()}", content_type='text/html')

@server.route("/", POST)
def buttonpress(request: Request):
    #  get the raw text
    request_content = request.json()
    print(request_content)
    image = decode_image(request_content["image"])
    boardid = request_content["boardID"]
    print("Starting UART write...")
    if uart_write(boardid, image):
        print("Finished UART write")

    return Response(request, f"{webpage()}", content_type='text/html')

print("starting server...")
# startup the server
try:
    server.start(str(wifi.radio.ipv4_address))
    print("Listening on http://%s:80" % wifi.radio.ipv4_address)
#  if the server fails to begin, restart the pico w
except OSError:
    time.sleep(5)
    print("restarting...")
    microcontroller.reset()

ping_address = ipaddress.ip_address("8.8.4.4")
clock = time.monotonic()
while True:
    try:
        if (clock + 30) < time.monotonic():
            if wifi.radio.ping(ping_address) is None:
                # print("Disconnected!")
                continue
            else:
                # print("Still connected")
                continue

            clock = time.monotonic()
        server.poll()
    except Exception as e:
        print(e)
        continue

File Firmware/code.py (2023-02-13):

import asyncio
import board
import digitalio
import neopixel
import struct

matrix = neopixel.NeoPixel(board.GP0, 25, brightness=1, auto_write=False)

sensor = digitalio.DigitalInOut(board.GP7)
sensor.direction = digitalio.Direction.INPUT
sensor.pull = digitalio.Pull.DOWN

frame_delay = 0.05 # Time between frames. Adjust to change playback speed
idle_brightness = 0.125
anim_brightness = 1

# Bitmap reading (with padding)
with open("bitmap/image.bmp", "rb") as f:
    # Read the file header
    f.seek(10)
    offset = struct.unpack("<i", f.read(4))[0]

    # Read the image header
    f.seek(18)
    width, height = struct.unpack("<ii", f.read(8))

    # Create a 2D array to store the pixel data
    pixels = [[(0, 0, 0) for _ in range(width)] for _ in range(height)]

    # Go to the pixel data
    f.seek(offset)

    # Read the pixel data
    for row in range(height - 1, -1, -1):
        for col in range(width):
            blue = ord(f.read(1))
            green = ord(f.read(1))
            red = ord(f.read(1))
            pixels[row][col] = (red, green, blue)

        # Calculate the number of padding bytes
        padding = (4 - (width * 3) % 4) % 4
        # Read the padding bytes and discard them
        f.read(padding)

pixels = sum(pixels, []) # Hacky magic to flatten the 2D list into a 1D list, because it doesn't need to be 2D.
                         # Will fix this later. Unless you're reading this, in which case it's a permanent feature now
frames = []
for i in range(0, len(pixels), 25):
    pixels[i + 5:i + 10] = pixels[i + 5:i + 10][::-1]   # The LED matrix is wired in alternating rows.
    pixels[i + 15:i + 20] = pixels[i + 15:i + 20][::-1] # As such, every 2nd "row" of each frame needs
    frames.append(pixels[i:i + 25])                     # to be mirrored.

ctrl = asyncio.Event() # Event to communicate whether the lights should be on or off to every async process
ctrl.clear() # Clear the event, so it's set as "False"
animation_task = None # Define the animation task as a global varbiale for ease of use. Don't cancel me for this, async is hard :(

async def animate(): # Self explanatory. Loops while animating
    matrix.brightness = anim_brightness
    while True:
        i = 0
        for frame in frames: # Loop through every frame, each made up of a 25 element long list holding the colour values for each pixel
            for dot in frame: # Loop through the colour values
                matrix[i] = dot # Assign the colour value to every LED in the matrix (actually just a strip of 25 LEDs chopped up, so we can treat it as one strip)
                i = 0 if (i+1) > 24 else i+1 # Necessary to prevent an index error
            matrix.show()
            await asyncio.sleep(frame_delay) # Async sleep, to make sure other code has time to run, as well as to keep the animation constrained to a certain speed
        await asyncio.sleep(0)

async def idle(): # Displays a single still frame, specifically the first frame in the animation, while panel isn't being held.
    i = 0
    for dot in frames[0]: # Only needs one loop because only the first frame is being accessed
        matrix[i] = dot   # Otherwise works identically to the animate() routine
        i = 0 if (i+1) > 24 else i+1 # Same deal as before
    matrix.brightness = idle_brightness
    matrix.show()

async def ctrl_detect():  # Constantly reads the state of the sensor pin to check if the panel should be animating.
    global animation_task # The signal is active high, so the 12V line that normally powers the panel's original LEDs
    while True:           # is going through a voltage divider to bring it down to a 3V "high" signal.
        if sensor.value:
            ctrl.set() # Set the "ctrl" event to "True" to tell the other subroutines that the animation should be playing
        else:
            ctrl.clear() # Clear the "ctrl" event to tell the other subroutines that the animation should stop, and the idle task should start
            if animation_task is not None: # Immediately stop the animation task if it's still playing.
                animation_task.cancel()    # Otherwise, the animation task and the idle task with clash,
                animation_task = None      # resulting in an unpleasant blinking effect.
                idle_task = asyncio.create_task(idle()) # Create and run the idle task.
                await idle_task
        await asyncio.sleep(0) # Allow other tasks time to execute

async def main(): # Main loop. Should be pretty self explanatory. Probably lots of redundant code here - might refactor later
    global animation_task
    idle_task = asyncio.create_task(idle())
    ctrl_task = asyncio.create_task(ctrl_detect())
    while True:
        if ctrl.is_set():
            if animation_task is None or animation_task.is_cancelled():
                animation_task = asyncio.create_task(animate())
            try:
                await animation_task
            except asyncio.CancelledError:
                pass
        else:
            await idle_task
        await asyncio.sleep(0)
    await asyncio.gather(ctrl_task, idle_task, animate_task)

asyncio.run(main())

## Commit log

2023-01-18 Initial schematics (Mainly RP2040)
    [Panel.kicad_pcb, Panel.kicad_sch, Power.kicad_pcb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]
2023-01-18 Initial component placement
    [Panel.kicad_pcb, Panel.kicad_sch]
2023-01-19 90% routed
    [Panel.kicad_pcb, Panel.kicad_sch]
2023-01-19 Complete panel PCB
    [Panel.kicad_pcb, Panel.kicad_sch]
2023-01-20 Final Panel changes + first prod run gerber
    [Panel-B_Cu.gbl, Panel-B_Mask.gbs, Panel-B_Paste.gbp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]
2023-01-20 Add more labels to PCB silkscreen, update README
    [Panel-B_Cu.gbl, Panel-B_Mask.gbs, Panel-B_Paste.gbp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]
2023-01-20 Initial power distribution PCB design
    [Power.kicad_pcb, Power.kicad_sch]
2023-01-24 Update power distribution PCB
    [Power.kicad_pcb, Power.kicad_sch]
2023-01-24 Power distribution PCB final rev. + gerber
    [Power-B_Cu.gbl, Power-B_Mask.gbs, Power-B_Paste.gbp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]
2023-01-26 Fix mirrored even rows, other misc things
    [code.py]
2023-01-27 Add power PCB info
2023-01-27 Fix critical issue - KiCad assigned LED pins wrong
    This would result in any boards manufactured with this design being unusable without cutting traces and bodging connections.
    [Panel-B_Cu.gbl, Panel-B_Mask.gbs, Panel-B_Paste.gbp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]
2023-01-27 Tidy up routing
    [Panel-B_Cu.gbl, Panel-B_Mask.gbs, Panel-B_Paste.gbp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]
2023-01-27 Fix hole alignment, tidy more routing
    [Panel-B_Cu.gbl, Panel-B_Mask.gbs, Panel-B_Paste.gbp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]
2023-01-27 Minor changes
    [Panel-B_Cu.gbl, Panel-B_Mask.gbs, Panel-B_Paste.gbp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]
2023-01-27 Hopefully final nitpicks and adjustments
    [Panel-B_Cu.gbl, Panel-B_Mask.gbs, Panel-B_Paste.gbp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]
2023-01-27 Fix major schematic issue and parity warnings
    [Panel-B_Cu.gbl, Panel-B_Mask.gbs, Panel-B_Paste.gbp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]
2023-01-27 Final touches (hopefully for real this time)
    [Panel-B_Cu.gbl, Panel-B_Mask.gbs, Panel-B_Paste.gbp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]
2023-01-31 Add output polarity labels to silkscreen
    [Power.kicad_pcb]
2023-01-31 Update power board gerbers
    [Power-B_Cu.gbl, Power-B_Mask.gbs, Power-B_Paste.gbp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]
2023-02-09 Add USB protection, GP25 LED, silkscreen tweaks
    [Panel-B_Cu.gbl, Panel-B_Mask.gbs, Panel-B_Paste.gbp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]
2023-02-10 Fix pin assignments
2023-02-13 Enlarge mounting holes slightly
    [Panel-B_Cu.gbl, Panel-B_Mask.gbs, Panel-B_Paste.gbp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]
2023-02-13 Minor silkscreen touchups
    [Panel-B_Cu.gbl, Panel-B_Mask.gbs, Panel-B_Paste.gbp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]
2023-02-15 Update to KiCAD 7, add ref designators to README
    [Panel.kicad_pcb, Panel.kicad_sch, Power.kicad_pcb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]
2023-06-14 Initial comms board design
    [Comms.kicad_pcb, Comms.kicad_sch]
2023-06-14 don't bridge 3v3 and ground lol
    [Comms.kicad_pcb, Comms.kicad_sch]
2023-08-03 Add RS485 functionality & addons, several fixes
    [Comms.kicad_pcb, Comms.kicad_sch, Controller.kicad_pcb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]
2023-08-03 Add voltage divider bypass for home pad use
    [Panel.kicad_pcb, Panel.kicad_sch]
2023-08-03 Fix an oopsie, control RE/DE via GPIO by default
    [Panel.kicad_pcb, Panel.kicad_sch]
2024-07-20 Replaced USB C port with cheaper alternative
    [Panel.kicad_pcb, Panel.kicad_sch]
2024-07-20 Fixed an unconnected track that was actually connected but still tripped DRC
    [Panel.kicad_pcb]
